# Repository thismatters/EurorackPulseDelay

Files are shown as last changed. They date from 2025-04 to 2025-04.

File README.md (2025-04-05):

# Pulse Delay

The circuit here is based on the [Yusynth Pulse Delay](https://yusynth.net/Modular/EN/PULSEDELAY/index.html) with minor tweaks to make it more Eurorack friendly. The changes I've made are thus:
* Selected resistors appropriate for +/-12V rails,
* Added polarity protection so that a backward power header doesn't fry anything (twin series schotty diodes: BAT54SL),
* Full surface mount design.

The Yusynth page is a treasure trove of information about this circuit that I am too amateur to claim as my own; please read that outstanding page before using this circuit. The page provides many details and other implementations of this circuit that you may find suitable.

The KiCAD project here uses the library/footprints [found in my companion repo](https://github.com/thismatters/EurorackKiCAD).

## Width

13hp on an Intellijel 1U rack.

## Inputs

Jack for gate/pulse input.

Knobs for:
* Pulse delay
* Pulse width

## Outputs

Jack for gate/pulse output.

LED to indicate output.

## Vendors

There are part numbers in the [BOM](pulse-delay.csv) for many of the parts (not for basic passives though) at the following vendors:

* [Mouser](https://www.mouser.com): Needs no introduction. Get your ICs from here (or [digikey](https://www.digikey.com)).
* [Tayda Electronics](https://www.taydaelectronics.com/): Good supplier for passive components; audio jacks, and potentiometers. Their audio jacks are slightly smaller than the thonkiconn from thonk.
* [Love My Switches](https://lovemyswitches.com/): Has [really good knobs](https://lovemyswitches.com/anodized-aluminum-knob-the-lo-fi-1-4-smooth-shaft-12-5mm-od/) to go on those potentiometers!
* [OSHPark](https://oshpark.com/): Fast and (relatively) cheap PCB manufacturer. Prototype run pending.

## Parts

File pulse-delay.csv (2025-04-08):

# | Reference | Qty | Value | Footprint | DNP | Vendor | PartNum
1 | C1, C2 | 2 | 22u 50V | Capacitor_THT:CP_Radial_D5.0mm_P2.50mm
2 | C3 | 1 | 10n | Capacitor_SMD:C_0805_2012Metric
3 | C4, C7 | 2 | 100n | Capacitor_SMD:C_0805_2012Metric
4 | C5, C6 | 2 | 1u box | Capacitor_THT:C_Rect_L7.2mm_W5.5mm_P5.00mm_FKS2_FKP2_MKS2_MKP2
5 | D1, D2 | 2 | BAT54S | Package_TO_SOT_SMD:SOT-23 |  | Mouser | 863-BAT54SLT1G
6 | D3, D4 | 2 | 1N4148 | Diode_SMD:D_SOD-323_HandSoldering
7 | D5 | 1 | LED_GREEN | LED_THT:LED_D3.0mm
8 | J1 | 1 | Conn_02x05_Odd_Even | Eurorack:PinHeader_2x05_P2.54mm_Vertical |  | Tayda | A-2939
9 | J2, J3 | 2 | AudioJack2_SwitchT | Eurorack:AudioJack2_Tayda_A-2566 |  | Tayda | A-2566
10 | Q1 | 1 | BCM847 | Package_SO:TSOP-6_1.65x3.05mm_P0.95mm |  | Mouser | 771-BCM847DS135
11 | R1, R2 | 2 | 10 | Resistor_SMD:R_0805_2012Metric
12 | R3 | 1 | 100K | Resistor_SMD:R_0805_2012Metric
13 | R4, R5 | 2 | 22K | Resistor_SMD:R_0805_2012Metric
14 | R6, R7, R10 | 3 | 10K | Resistor_SMD:R_0805_2012Metric
15 | R8 | 1 | 1K | Resistor_SMD:R_0805_2012Metric
16 | R9 | 1 | 1.8K | Resistor_SMD:R_0805_2012Metric
17 | RV1, RV2 | 2 | A1M | Eurorack:Potentiometer_RV16AF-41-15R1
18 | U1 | 1 | 4538 | Package_SO:TSSOP-16_4.4x5mm_P0.65mm |  | Mouser | 595-CD14538BPWR

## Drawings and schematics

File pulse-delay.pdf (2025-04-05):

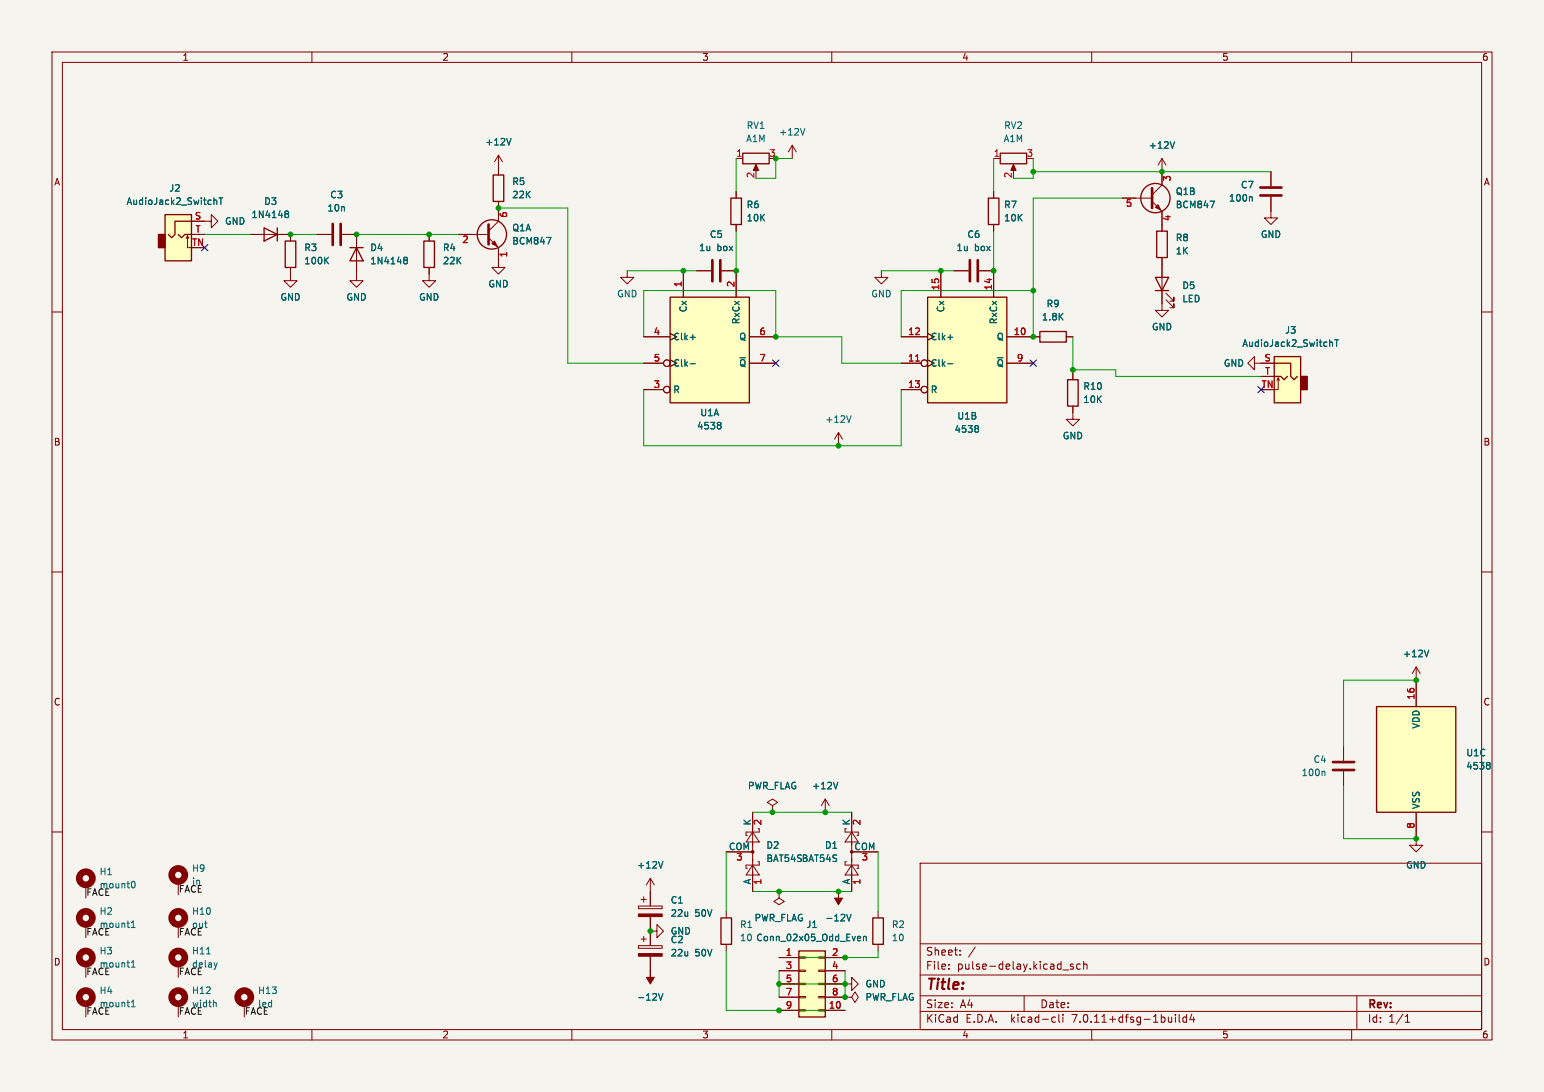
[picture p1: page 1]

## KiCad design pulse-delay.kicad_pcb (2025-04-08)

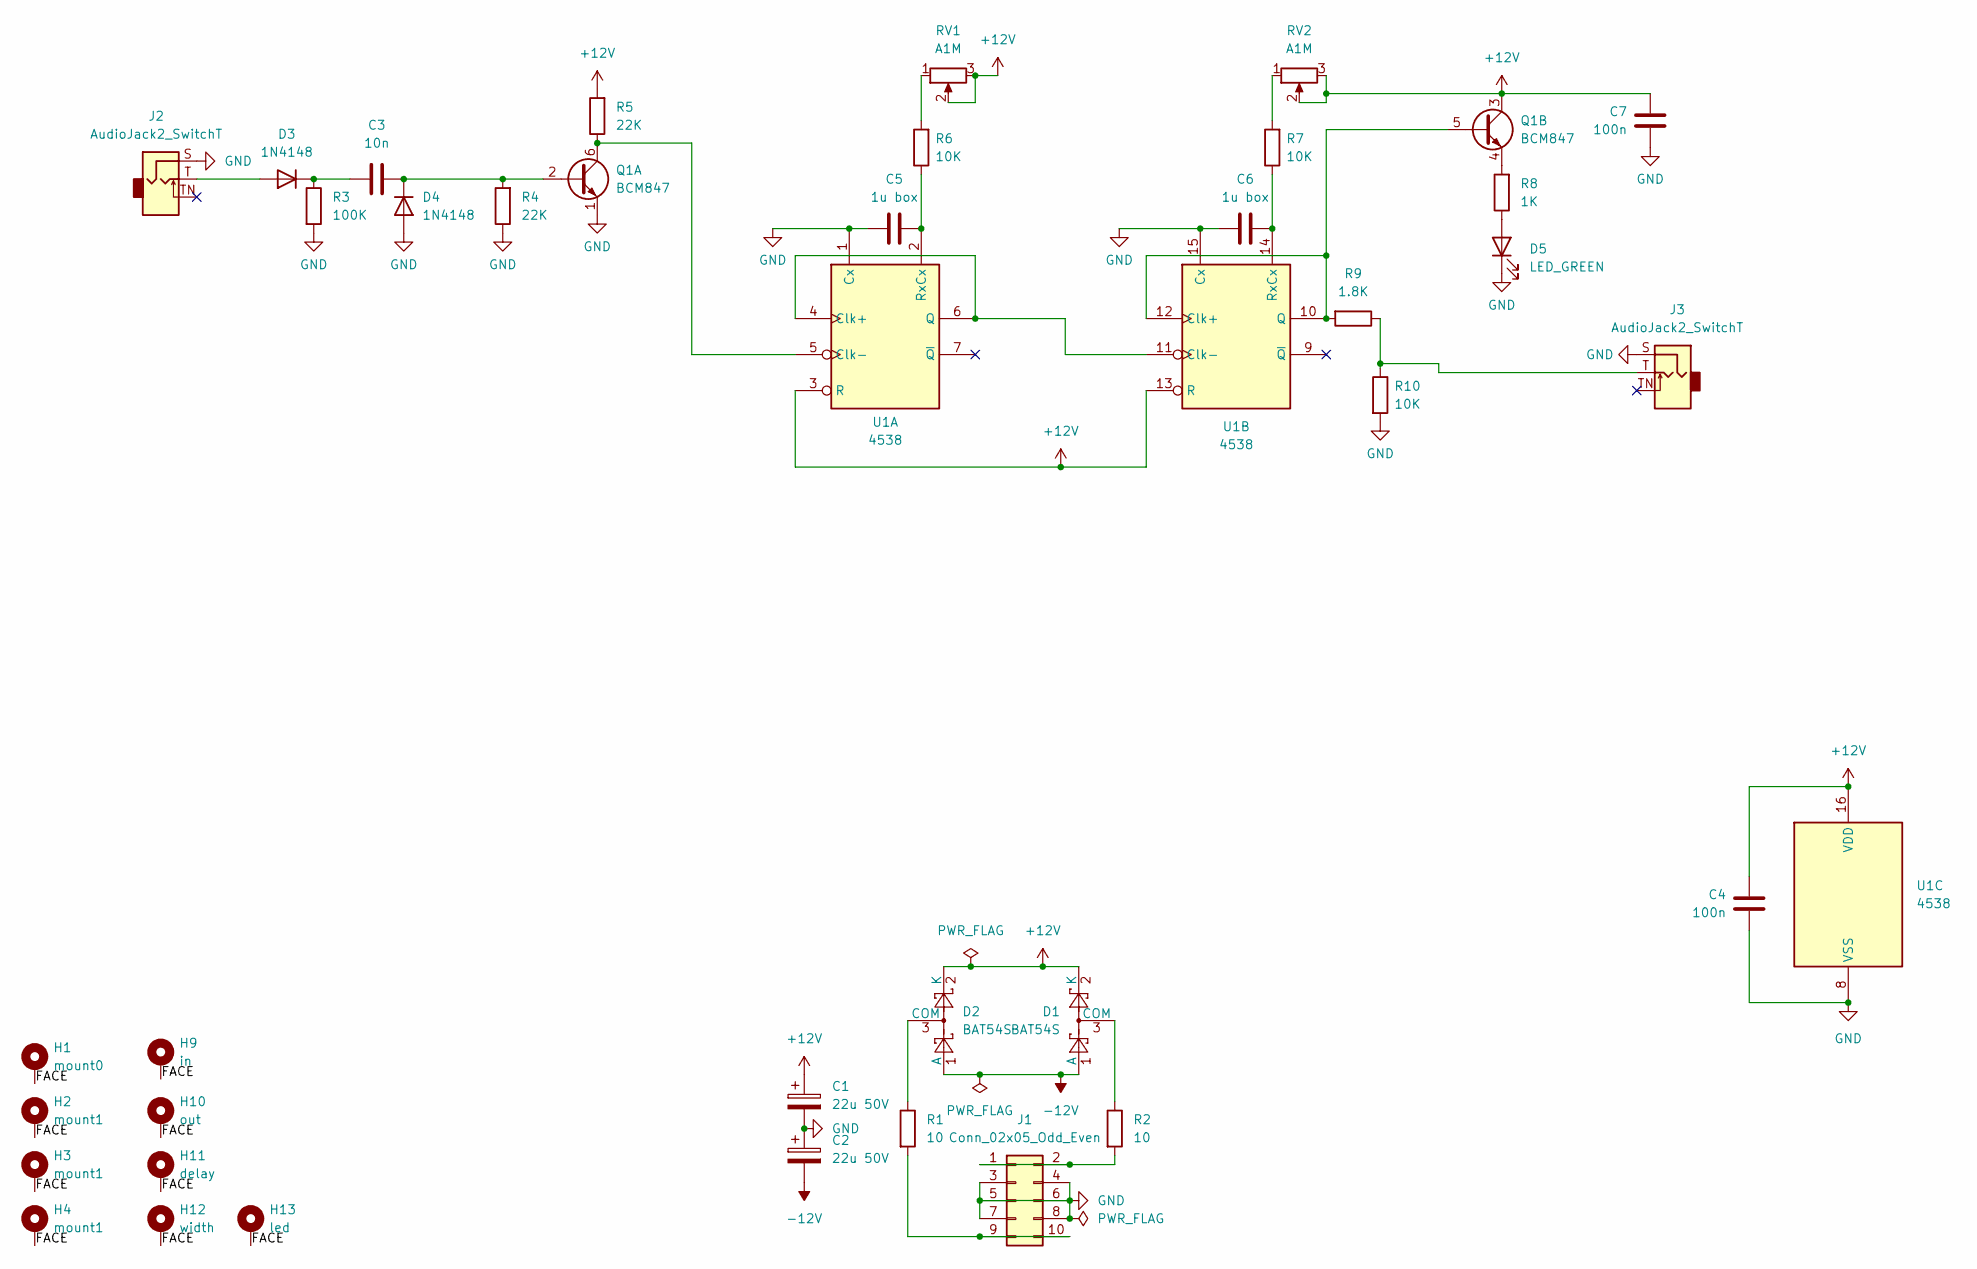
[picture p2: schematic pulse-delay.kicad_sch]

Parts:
C1, C2: 22u 50V; CP_Radial_D5.0mm_P2.50mm
C3: 10n; C_0805_2012Metric
C4, C7: 100n; C_0805_2012Metric
C5, C6: 1u box; C_Rect_L7.2mm_W5.5mm_P5.00mm_FKS2_FKP2_MKS2_MKP2
D1, D2: BAT54S; SOT-23; PartNum 863-BAT54SLT1G
D3, D4: 1N4148; D_SOD-323_HandSoldering
D5: LED_GREEN; LED_D3.0mm
H1: mount0; Mech-MountingHole
H2, H3, H4: mount1; Mech-MountingHole
H9: in; Mech-AudioJack-Hole-Input-Gate
H10: out; Mech-AudioJack-Hole-Output-Gate
H11: delay; Mech-Potentiometer-Hole_level_90deg
H12: width; Mech-Potentiometer-Hole_level_90deg
H13: led; Mech-LED-Hole-3mm-Bezel
J1: Conn_02x05_Odd_Even; PinHeader_2x05_P2.54mm_Vertical; PartNum A-2939
J2, J3: AudioJack2_SwitchT; AudioJack2_Tayda_A-2566; PartNum A-2566
Q1: BCM847; TSOP-6_1.65x3.05mm_P0.95mm; PartNum 771-BCM847DS135
R1, R2: 10; R_0805_2012Metric
R3: 100K; R_0805_2012Metric
R4, R5: 22K; R_0805_2012Metric
R6, R7, R10: 10K; R_0805_2012Metric
R8: 1K; R_0805_2012Metric
R9: 1.8K; R_0805_2012Metric
RV1, RV2: A1M; Potentiometer_RV16AF-41-15R1
U1: 4538; TSSOP-16_4.4x5mm_P0.65mm; PartNum 595-CD14538BPWR

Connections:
+12V: C1.1, C4.1, C7.1, D1.2 (K), D2.2 (K), Q1.3 (C2), R5.2, RV1.2, RV1.3, RV2.2, RV2.3, U1.3 (R), U1.13 (R), U1.16 (VDD)
-12V: C2.2, D1.1 (A), D2.1 (A)
/FACE: H1.1, H2.1, H3.1, H4.1, H9.1, H10.1, H11.1, H12.1, H13.1
GND: C1.2, C2.1, C4.2, C5.1, C6.1, C7.2, D4.2 (A), D5.1 (K), J1.3, J1.4, J1.5, J1.6, J1.7, J1.8, J2.S, J3.S, Q1.1 (E1), R3.2, R4.1, R10.2, U1.1 (Cx), U1.8 (VSS), U1.15 (Cx)
unnamed: D1.3 (COM), R2.1
unnamed: D2.3 (COM), R1.1
unnamed: D3.2 (A), J2.T
unnamed: C3.1, D3.1 (K), R3.1
unnamed: C3.2, D4.1 (K), Q1.2 (B1), R4.2
unnamed: D5.2 (A), R8.1
unnamed: J1.1, J1.2, R2.2
unnamed: J1.9, J1.10, R1.2
unnamed: J3.T, R9.1, R10.1
unnamed: Q1.6 (C1), R5.1, U1.5 (Clk-)
unnamed: Q1.5 (B2), R9.2, U1.10 (Q), U1.12 (Clk+)
unnamed: Q1.4 (E2), R8.2
unnamed: R6.2, RV1.1
unnamed: R7.2, RV2.1
unnamed: U1.4 (Clk+), U1.6 (Q), U1.11 (Clk-)
unnamed: C5.2, R6.1, U1.2 (RxCx)
unnamed: C6.2, R7.1, U1.14 (RxCx)

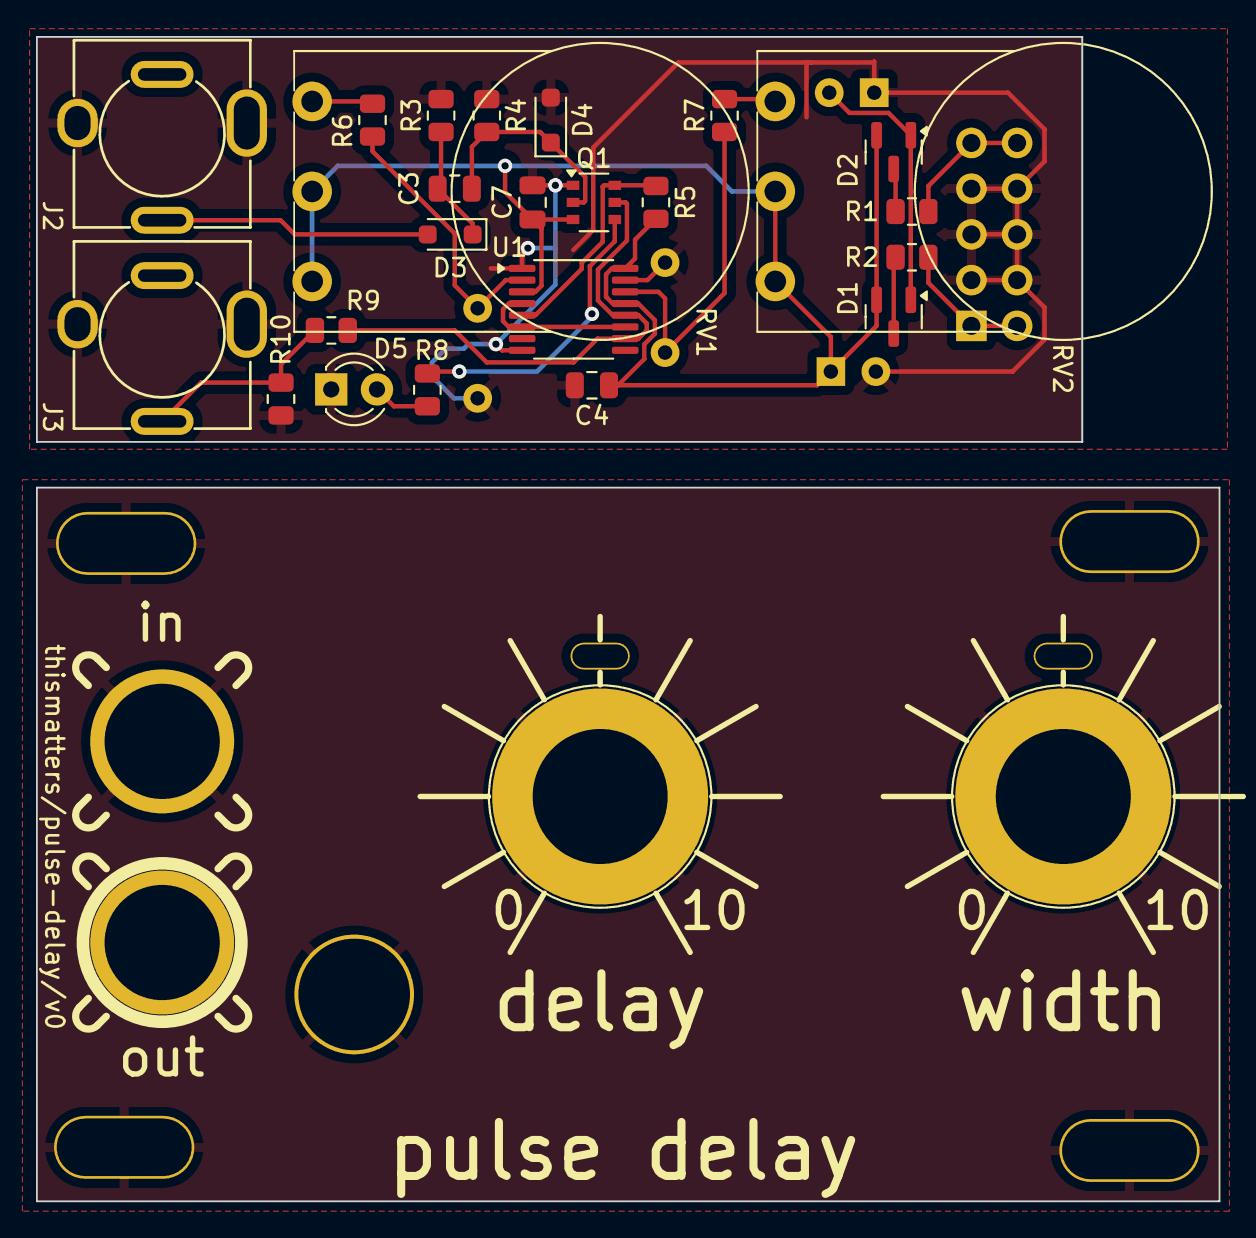
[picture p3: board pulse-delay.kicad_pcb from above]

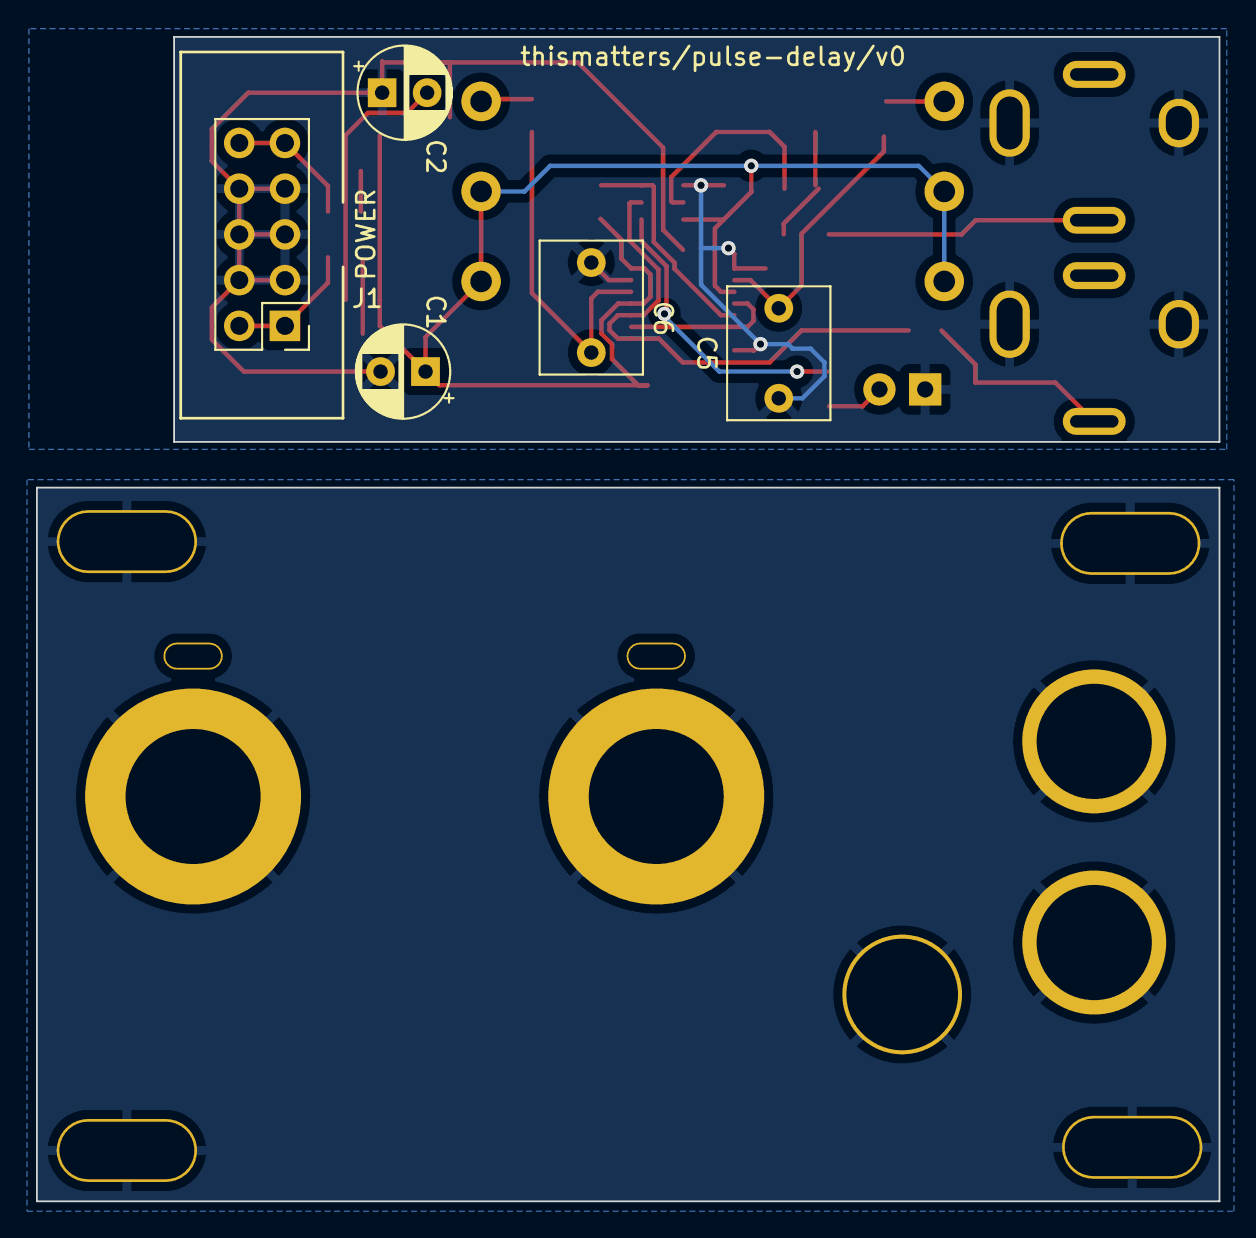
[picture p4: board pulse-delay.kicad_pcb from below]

Board: 2 copper layers, 65.7 x 64.7 mm, 38 parts (5 on the bottom side), 21 nets.

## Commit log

2025-04-05 pcb ready for v0
    [pulse-delay.csv, pulse-delay.kicad_pcb, pulse-delay.kicad_sch]
2025-04-08 update bom
    [pulse-delay.csv, pulse-delay.kicad_pcb, pulse-delay.kicad_sch]
